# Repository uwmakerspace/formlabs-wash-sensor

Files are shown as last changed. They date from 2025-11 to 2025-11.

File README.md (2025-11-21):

# Formlabs Wash Sensor

This repository contains the firmware and documentation for the Design Innovation Lab's Formlabs Wash Sensor. This device is designed to monitor multiple Formlabs Wash units and visually alert when a wash has completed.

The device uses a distance sensor to measure the position of the wash basket. If the sensor detects the back wall, it assumes the machines are empty or currently working. If it detects an object (the basket/print) consistently, it illuminates a WS2812B LED strip to indicate presence and position, providing visual feedback in busy environments.

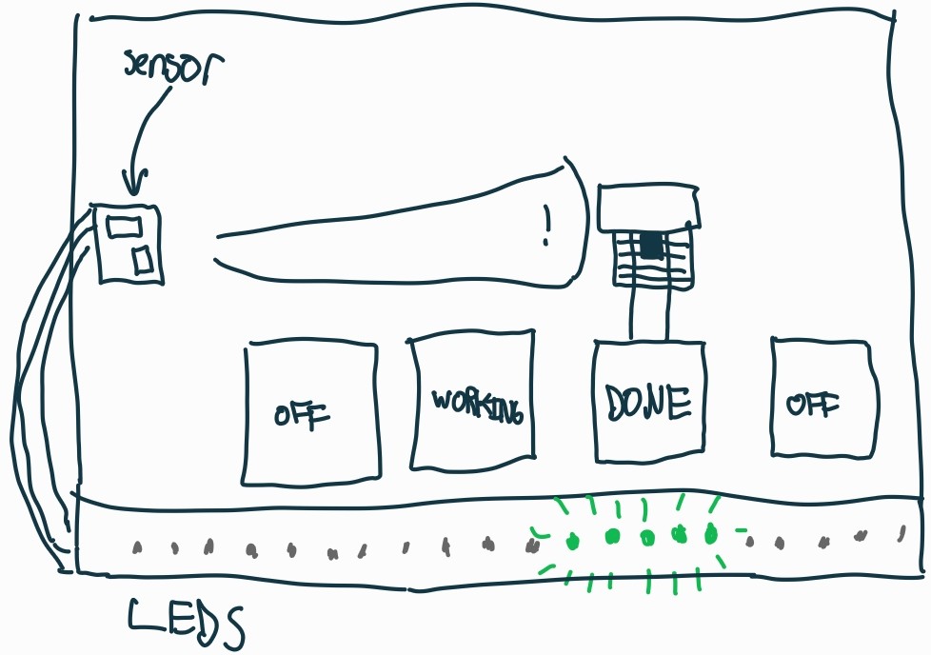
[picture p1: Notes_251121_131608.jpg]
Visual diagram


## Features

- **Non-Contact Sensing:** Utilizes the VL53L0X time-of-flight distance sensor for measurement. Non-contact sensing avoids mechanical wear and resin contamination. One sensor can monitor multiple wash stations.
- **Visual Feedback:**
  - **Position Tracking:** NeoPixel strip indicates which of the wash stations needs attention based on the distance reading.
  - **Effects:** A "breathing" effect and a bi-directional pulse effect enhance visibility.
- **Noise Filtering:**
  - **Exponential Moving Average (EMA):** Heavily smooths sensor jitter
  - **Hysteresis:** "Sticky" LED positioning prevents flickering between pixels.
- **Smart Presence Detection:** Includes a 15-second delay. The LEDs will not trigger during transient events (like loading or unloading a print). The object must be detected for 15 seconds before the display activates.

## Hardware

- **Microcontroller:** ESP32-C3 "Super Mini" board
- **Sensor:** VL53L0X Time-of-Flight Distance Sensor module
- **Display:** WS2812B Addressable LED Strip

## PCB

A custom PCB was designed to integrate the components neatly and flatly against the wall. The PCB files can be found in the `kicad/` directory. It's simply mounted against the wall using double-sided tape. Nothing special about it, just better than a bunch of wires. Uses Osh Park design rules.

## Configuration

- `WALL_DISTANCE`: The distance from the sensor to the back wall. Readings beyond this turn the system off.
- `FIRST_LED_DISTANCE_OFFSET`: Distance from the sensor to the first LED on the strip.
- `SENSOR_DETECTION_OFFSET`: Compensates for the sensor detecting the front edge of an object while the LEDs should represent the center.
- `LED_SPACING`: Physical distance between LED pixels.
- `PRESENCE_TIMEOUT`: Time an object must be consistently seen before LEDs turn on.
- `FILTER_ALPHA`: Smoothing factor. Lower is smoother but slower.
- `HYSTERESIS_THRESHOLD`: How far the object must move to shift the LED pixel.

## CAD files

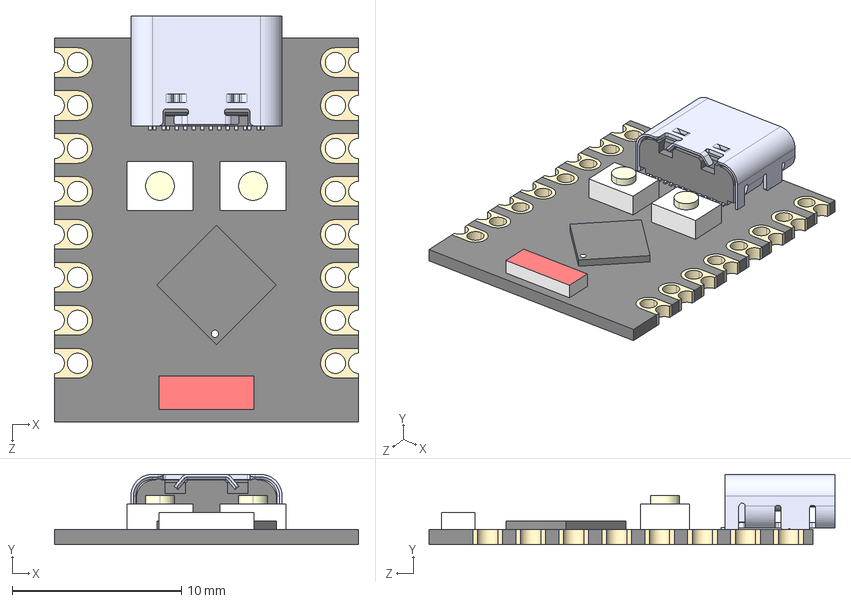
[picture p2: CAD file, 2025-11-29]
kicad/ESP32-C3_SUPERMINI_SMD.step
18.0 x 4.16 x 24.0 mm
Board c3mini
USB C
components (other)^ESP32-C3 SuperMini

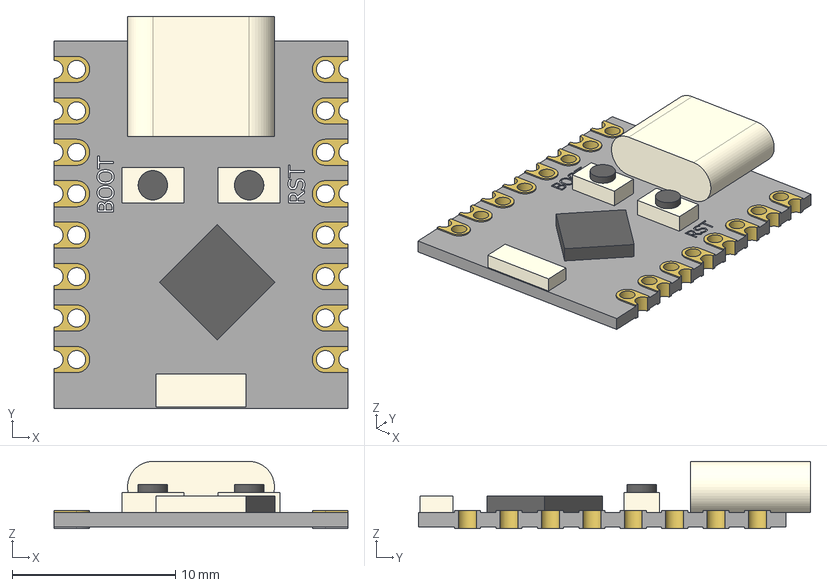
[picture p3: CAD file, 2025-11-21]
kicad/ESP32C3-SuperMini.stp
18.0 x 24.0 x 4.12 mm

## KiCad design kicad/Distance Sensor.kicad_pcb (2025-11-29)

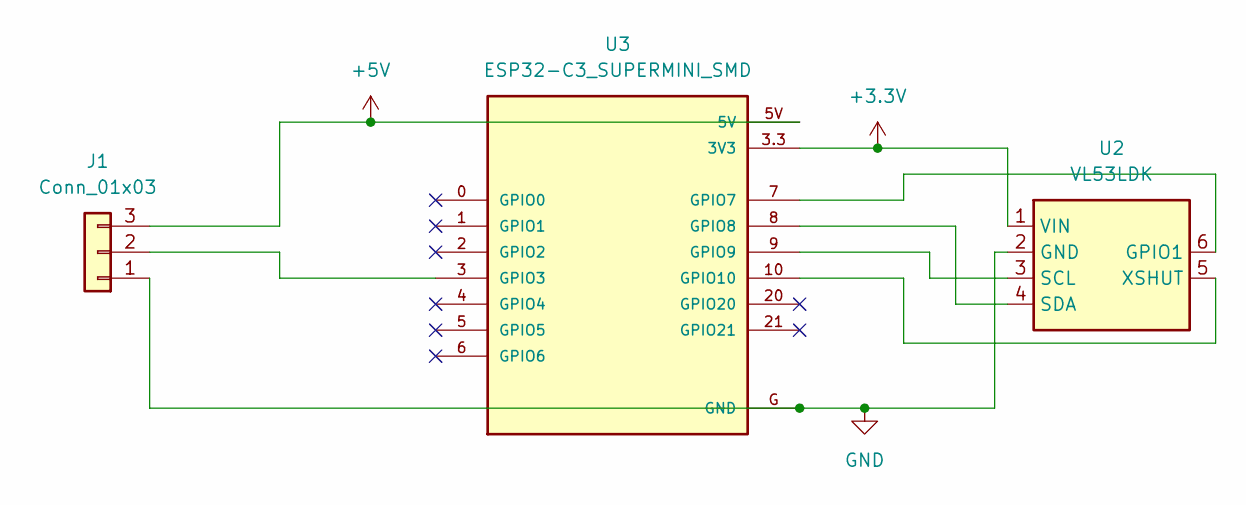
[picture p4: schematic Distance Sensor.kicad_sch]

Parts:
J1: Conn_01x03; PinHeader_1x03_P2.54mm_Vertical
U2: VL53LDK
U3: ESP32-C3_SUPERMINI_SMD; MODULE_ESP32-C3_SUPERMINI

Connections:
+3.3V: U2.1 (VIN), U3.3.3 (3V3)
+5V: J1.3, U3.5V
GND: J1.1, U2.2 (GND), U3.G (GND)
unnamed: J1.2, U3.3 (GPIO3)
unnamed: U2.6 (GPIO1), U3.7 (GPIO7)
unnamed: U2.3 (SCL), U3.9 (GPIO9)
unnamed: U2.4 (SDA), U3.8 (GPIO8)
unnamed: U2.5 (XSHUT), U3.10 (GPIO10)

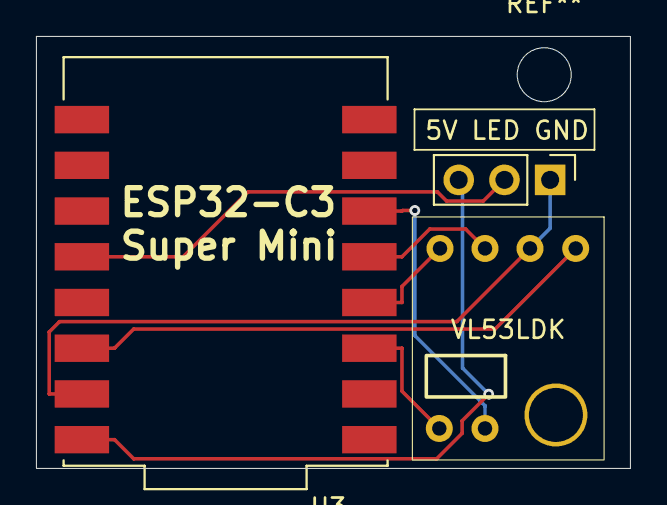
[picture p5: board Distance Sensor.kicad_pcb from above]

Board: 2 copper layers, 33.0 x 24.0 mm, 4 parts (1 on the bottom side), 8 nets.

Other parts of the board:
kibuzzard-68CD61BF: G***; kibuzzard-68CD61BF

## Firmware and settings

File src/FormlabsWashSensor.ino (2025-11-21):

#include <Arduino.h>
#include <FastLED.h>
#include <VL53L0X.h>
#include <Wire.h>

#define CM 10

// --- Hardware Configuration ---
#define DATA_PIN 3
#define NUM_LEDS 42

// --- Physical Layout ---
#define INDICATOR_WIDTH 9
#define FIRST_LED_DISTANCE_OFFSET (12 * CM)  // First LED is 12cm in front of sensor
#define SENSOR_DETECTION_OFFSET (2 * CM)     // Sensor hits object 2cm past real edge of wash station
#define LED_SPACING 33                       // Pixel-to-pixel distance (mm)

// --- Range Settings ---
#define WALL_DISTANCE (155 * CM)
#define WALL_MARGIN (2 * CM)
#define LONG_RANGE_MODE

// --- Timing & Filtering ---
#define FILTER_ALPHA 0.05          // Lower = smoother but slower
#define MAX_INVALID_READINGS 15    // ~0.5s before considering signal lost
#define PRESENCE_TIMEOUT 15000     // 15s wait before activating LEDs
#define HYSTERESIS_THRESHOLD 0.90  // How far (LEDs) to move before shifting indicator

// --- Animation Settings ---
#define BREATH_BPM 20
#define BREATH_MIN 40
#define BREATH_MAX 255
#define PULSE_INTERVAL 6000
#define PULSE_SPEED_PX_MS 0.04f

// --- Global Objects ---
VL53L0X sensor;
CRGB leds[NUM_LEDS];

// --- State Structures ---

struct SensorState {
    float smoothedDistance = -1;  // -1 indicates uninitialized
    int invalidCount = 0;
};

struct LogicState {
    unsigned long presenceStartTime = 0;  // 0 means object not present
    int currentCenterIndex = -1;          // -1 means no valid position
};

struct PulseState {
    unsigned long lastTrigger = 0;
    unsigned long startTime = 0;
    bool active = false;
};

SensorState sensorState;
LogicState logicState;
PulseState pulseState;

// --- Function Prototypes ---
void setupSensor();
bool updateSensorData();
void resetSystemState();
bool isObjectPresentForDuration();
int calculateLedIndex(float distanceMm);
void renderVisuals(int centerIndex);

void setup() {
    Serial.begin(9600);
    Wire.begin();
    FastLED.addLeds<WS2812B, DATA_PIN, GRB>(leds, NUM_LEDS);
    setupSensor();
}

void loop() {
    // 1. Read and filter sensor data
    // Returns false if the sensor has been invalid (error/out of range) for too long
    if (!updateSensorData()) {
        resetSystemState();
        FastLED.show();
        return;
    }

    // 2. Check if we are hitting the back wall (disable indicator)
    if (sensorState.smoothedDistance >= WALL_DISTANCE - WALL_MARGIN) {
        resetSystemState();
        FastLED.show();
        return;
    }

    // 3. Check 15-second presence timer
    if (!isObjectPresentForDuration()) {
        fill_solid(leds, NUM_LEDS, CRGB::Black);
        FastLED.show();
        return;
    }

    // 4. Calculate center LED position (physics & hysteresis)
    int centerIndex = calculateLedIndex(sensorState.smoothedDistance);

    // 5. Render effects (breathing, falloff, pulse)
    renderVisuals(centerIndex);

    FastLED.show();
}

// --- Helper Functions ---

void setupSensor() {
    sensor.setTimeout(500);
    if (!sensor.init()) {
        Serial.println(F("Failed to detect and initialize sensor!"));
        while (1) {
        }
    }

#if defined LONG_RANGE_MODE
    sensor.setSignalRateLimit(0.1);
    sensor.setVcselPulsePeriod(VL53L0X::VcselPeriodPreRange, 18);
    sensor.setVcselPulsePeriod(VL53L0X::VcselPeriodFinalRange, 14);
#endif

    // 33ms budget for ~30Hz updates
    sensor.setMeasurementTimingBudget(33000);
    sensor.startContinuous();
}

// Returns true if we have valid data to show (even if it's slightly stale),
// Returns false if data has been invalid for > MAX_INVALID_READINGS.
bool updateSensorData() {
    int rawDistance = sensor.readRangeContinuousMillimeters();
    bool isError = sensor.timeoutOccurred() || rawDistance == 0 || rawDistance > 8000;

    if (isError) {
        sensorState.invalidCount++;
        if (sensorState.invalidCount > MAX_INVALID_READINGS) {
            return false;  // Too many errors, system should reset
        }
        // If errors are few, we implicitly return 'true' but DO NOT update smoothedDistance.
        // This freezes the display at the last known good position.
    } else {
        // Valid reading
        sensorState.invalidCount = 0;
        // EMA Filter
        if (sensorState.smoothedDistance < 0) {
            sensorState.smoothedDistance = rawDistance;
        } else {
            sensorState.smoothedDistance = (FILTER_ALPHA * rawDistance) + ((1.0 - FILTER_ALPHA) * sensorState.smoothedDistance);
        }
        Serial.printf("raw: %i mm (smoothed: %i mm)\n", rawDistance, (int)sensorState.smoothedDistance);
    }
    return true;
}

void resetSystemState() {
    fill_solid(leds, NUM_LEDS, CRGB::Black);
    sensorState.smoothedDistance = -1;
    sensorState.invalidCount = 0;
    logicState.presenceStartTime = 0;
    logicState.currentCenterIndex = -1;
}

bool isObjectPresentForDuration() {
    // Initialize timer if this is the first frame of detection
    if (logicState.presenceStartTime == 0) {
        logicState.presenceStartTime = millis();
        if (logicState.presenceStartTime == 0) logicState.presenceStartTime = 1;  // Safety
    }

    return (millis() - logicState.presenceStartTime >= PRESENCE_TIMEOUT);
}

int calculateLedIndex(float distanceMm) {
    int trueDistance = (int)distanceMm - SENSOR_DETECTION_OFFSET;
    float rawIndex = (float)(trueDistance - FIRST_LED_DISTANCE_OFFSET) / LED_SPACING;

    // Hysteresis Logic
    if (logicState.currentCenterIndex == -1) {
        // First run, snap immediately
        logicState.currentCenterIndex = (int)round(rawIndex);
    } else {
        float diff = rawIndex - logicState.currentCenterIndex;

        // Sticky threshold: only move if we cross threshold
        if (diff > HYSTERESIS_THRESHOLD) {
            logicState.currentCenterIndex++;
        } else if (diff < -HYSTERESIS_THRESHOLD) {
            logicState.currentCenterIndex--;
        }

        // Fast movement catch-up
        // Noise spikes < 2.5 LEDs wide won't break the stickiness.
        if (abs(diff) > 2.5) {
            logicState.currentCenterIndex = (int)round(rawIndex);
        }
    }
    return logicState.currentCenterIndex;
}

void renderVisuals(int centerIndex) {
    int halfWidth = INDICATOR_WIDTH / 2;
    uint8_t breathBrightness = beatsin8(BREATH_BPM, BREATH_MIN, BREATH_MAX);
    unsigned long now = millis();

    // 1. Base indicator with quadratic falloff
    for (int i = 0; i < NUM_LEDS; i++) {
        int d = abs(i - centerIndex);

        if (d <= halfWidth) {
            // Calculate falloff (center=1.0, edge=0.0)
            float ratio = (float)d / halfWidth;
            float factor = 1.0f - ratio;
            float quadFactor = factor * factor;  // Quadratic curve

            uint8_t baseVal = (uint8_t)(255 * quadFactor);
            uint8_t finalVal = scale8(baseVal, breathBrightness);

            leds[i] = CRGB(0, finalVal, 0);
        } else {
            leds[i] = CRGB::Black;
        }
    }

    // 2. Pulse Logic
    if (!pulseState.active && (now - pulseState.lastTrigger > PULSE_INTERVAL)) {
        pulseState.active = true;
        pulseState.startTime = now;
        pulseState.lastTrigger = now;
    }

    if (pulseState.active) {
        int offset = (int)((now - pulseState.startTime) * PULSE_SPEED_PX_MS);

        int leftPos = (centerIndex - halfWidth) - offset;
        int rightPos = (centerIndex + halfWidth) + offset;
        bool visible = false;

        if (leftPos >= 0 && leftPos < NUM_LEDS) {
            leds[leftPos] += CRGB::White;
            visible = true;
        }
        if (rightPos >= 0 && rightPos < NUM_LEDS) {
            leds[rightPos] += CRGB::White;
            visible = true;
        }

        // Terminate pulse if it travels off screen
        if (offset > NUM_LEDS && !visible) {
            pulseState.active = false;
        }
    }
}
